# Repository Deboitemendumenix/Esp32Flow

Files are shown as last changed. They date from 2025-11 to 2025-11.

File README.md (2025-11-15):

# 💧 ESP32 Uroflowmetry Station

This project transforms an **ESP32** microcontroller and an **HX711** load cell amplifier into a web-enabled Uroflowmetry/Flow-Rate measurement device. It captures weight data over time, calculates the flow rate, and provides a web interface (HTML chart) and a CSV download for result analysis.

## ✨ Features

* **Wireless Data Acquisition:** Uses ESP32 Wi-Fi capabilities to host a web server for control and results.
* **High-Resolution Weighing:** Integrates the **HX711** Load Cell Amplifier for precise weight measurements.
* **Automatic Measurement Control:**
    * **Start Condition:** Measurement automatically begins when a weight greater than the `START_THRESHOLD` is detected.
    * **Stop Condition:** Measurement automatically stops after a period of stable weight (`STOP_TIMEOUT` and `STABILITY_TOLERANCE`).
* **Web Interface:** Serves a simple control page and a results page with an interactive **Google Chart** of Flow Rate and Volume over time.
* **Data Export:** Allows direct download of measurement data as a **CSV** file.
* **Status Indication:** Uses an **RGB LED** to visually indicate the device's current state.

---

## 🛠️ Hardware Requirements

* **ESP32 Development Board** (e.g., ESP32-WROOM-32)
* **HX711 Load Cell Amplifier**
* **1kg Load Cell**
* **RGB LED** or three single LEDs (common cathode/anode, adjust code accordingly)
* **Protoboard (5x7cm)**: Needed for mounting and wiring the components to fit within the case.
* **Power Supply** and associated wiring components.

---

## 📦 3D-Printed Case and Assembly

The project enclosure can be 3D printed using the provided files.

* The required **3mf files** are located in the **`models/`** folder of this repository.
* **Internal Components:** The case is designed to accommodate a **5x7cm protoboard** for mounting the ESP32 and HX711 components.
* **Assembly Hardware:** You will need the following screws for assembly:
    * **2x M4 screws** (16mm length)
    * **2x M5 screws** (16mm length)

---

## 📌 Pin Configuration

The following GPIO pins are used in the provided code.

| Component | Pin (GPIO) | Constant Name |
| :--- | :--- | :--- |
| **HX711 DOUT** | 18 | `LOADCELL_DOUT_PIN` |
| **HX711 SCK** | 16 | `LOADCELL_SCK_PIN` |
| **RGB LED Red** | 22 | `redPin` |
| **RGB LED Green** | 21 | `greenPin` |
| **RGB LED Blue** | 19 | `bluePin` |

---

## ⚙️ Setup and Calibration

### 1. Libraries

This project requires the following Arduino libraries:

* **HX711 Library** (e.g., from Bogdan R. or similar, commonly available in the Arduino Library Manager).
* **WiFi** (built-in for ESP32)
* **WebServer** (built-in for ESP32, usually found as `WebServer.h`)

### 2. Configuration

Before uploading, modify the following constants in the code (`#include <Arduino.h>...` section):

| Constant | Description | Default Value |
| :--- | :--- | :--- |
| `ssid` | Your Wi-Fi network name. | `"xxx"` |
| `password` | Your Wi-Fi network password. | `"xxx"` |
| `staticIP` | Static IP address. Leave empty `""` for DHCP (router-assigned), or specify an IP like `"192.168.1.100"`. | `""` (DHCP) |
| `gatewayIP` | Router gateway IP (used only if `staticIP` is configured). | `"192.168.1.1"` |
| `subnetMask` | Network subnet mask (used only if `staticIP` is configured). | `"255.255.255.0"` |
| `dnsServer` | DNS server (used only if `staticIP` is configured). | `"8.8.8.8"` |
| `CALIBRATION_FACTOR` | **Crucial:** Your load cell's specific calibration value (units per gram). **Must be determined experimentally.** | `-1025.42` |
| `START_THRESHOLD` | Minimum weight (in grams) to begin recording. | `1.0` |
| `STOP_TIMEOUT` | Duration (in ms) of stability before stopping the recording. | `10000` (10 seconds) |
| `STABILITY_TOLERANCE` | Allowable weight change (in grams) during the stop check. | `1.0` |

### 3. Calibration Process

You **must** calibrate your load cell/HX711 setup to find the correct `CALIBRATION_FACTOR`.

1.  Temporarily set `CALIBRATION_FACTOR` to `1.0`.
2.  Upload the code. The serial monitor will show the raw reading.
3.  Place a known weight (e.g., 100g) on the scale.
4.  The value printed to the serial monitor is your **Raw Reading**.
5.  Calculate the factor: **`CALIBRATION_FACTOR` = (Known Weight) / (Raw Reading)**. (Note: The result may be negative depending on your wiring).
6.  Replace the placeholder value with your calculated factor and upload the code again.

---

## 🚀 Usage

1.  **Connect Power:** Power up the ESP32.
2.  **Connect to Wi-Fi:** The device will attempt to connect to the configured Wi-Fi network.
3.  **Find IP:** Check the Serial Monitor to find the assigned **IP Address** or check your router to find the IP.
4.  **Access Web Server:** Open a web browser and navigate to the assigned IP address (e.g., `http://192.168.1.100`).
5.  **Control Page:** Click the **"Reset & Start New Measurement"** button. This tares the scale and sets the state to **IDLE**.
6.  **Measurement:** Place the object to be measured on the scale. Once the weight exceeds the `START_THRESHOLD`, the device will enter the **MEASURING** state and begin logging data.
7.  **Results:** Once the weight is stable for the `STOP_TIMEOUT`, the test will enter the **COMPLETED** state. View or download the results using the links on the main page.

---

## 🚥 Status Colors (RGB LED)

The RGB LED provides a quick visual indication of the system's status:

| State | Color | Description |
| :--- | :--- | :--- |
| `OFFLINE` | **Red** | Wi-Fi is disconnected or attempting to connect. |
| `IDLE` | **Green** | Ready for measurement. Awaiting weight change. |
| `MEASURING` | **Orange** | Actively recording weight and calculating flow rate. |
| `COMPLETED` | **Blue** | Measurement is complete and results are available. |
| `ERROR` | **Magenta** | Measurement was interrupted by a Wi-Fi disconnect. |

---

## 🖼️ Pictures

### Device

<div style="display:flex; gap:12px; align-items:center; flex-wrap:wrap;">
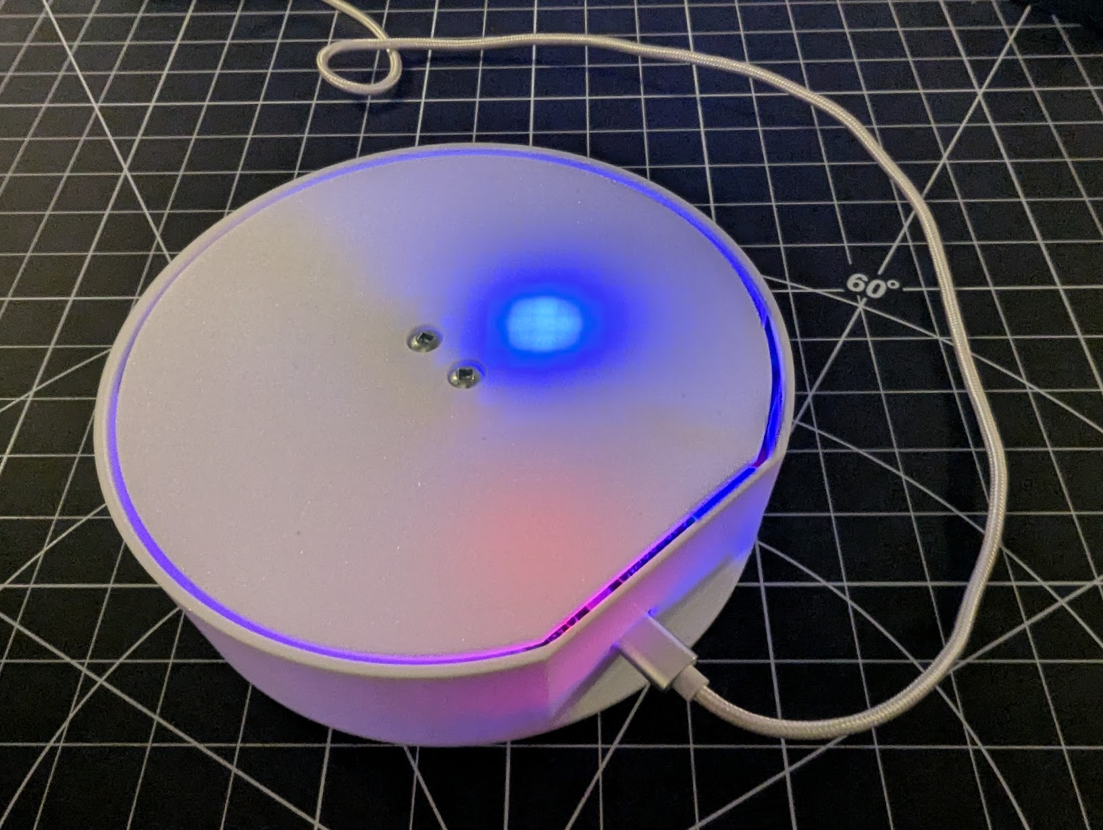
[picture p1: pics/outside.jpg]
OUtside view
    
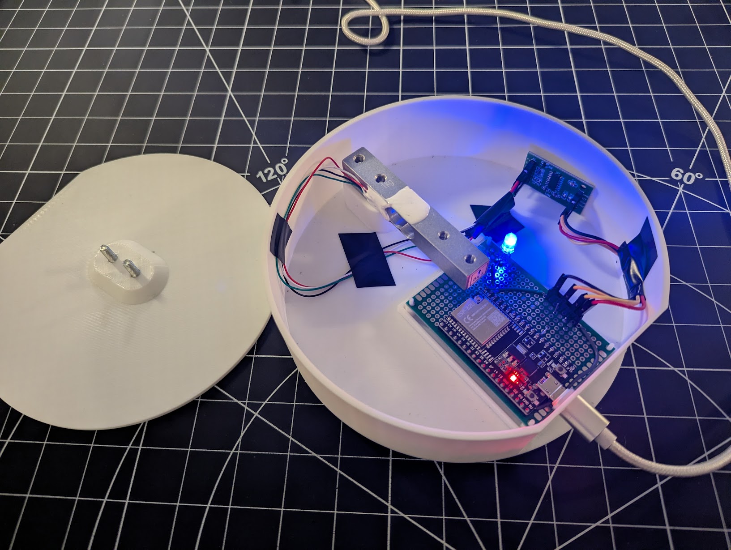
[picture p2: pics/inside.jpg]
Inside view
    
</div>

### Web interface

<div style="display:flex; gap:12px; align-items:center; flex-wrap:wrap;">
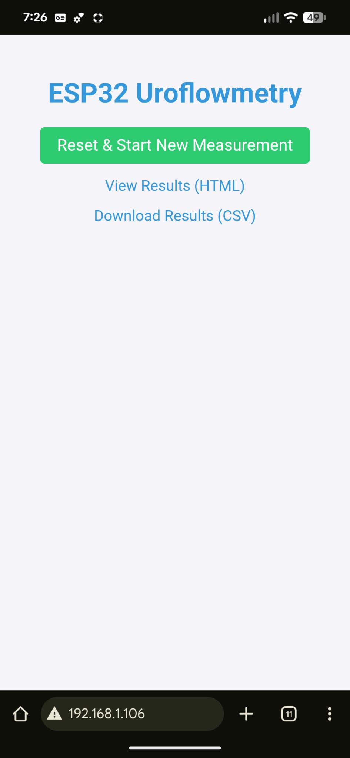
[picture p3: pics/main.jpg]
Main view
    
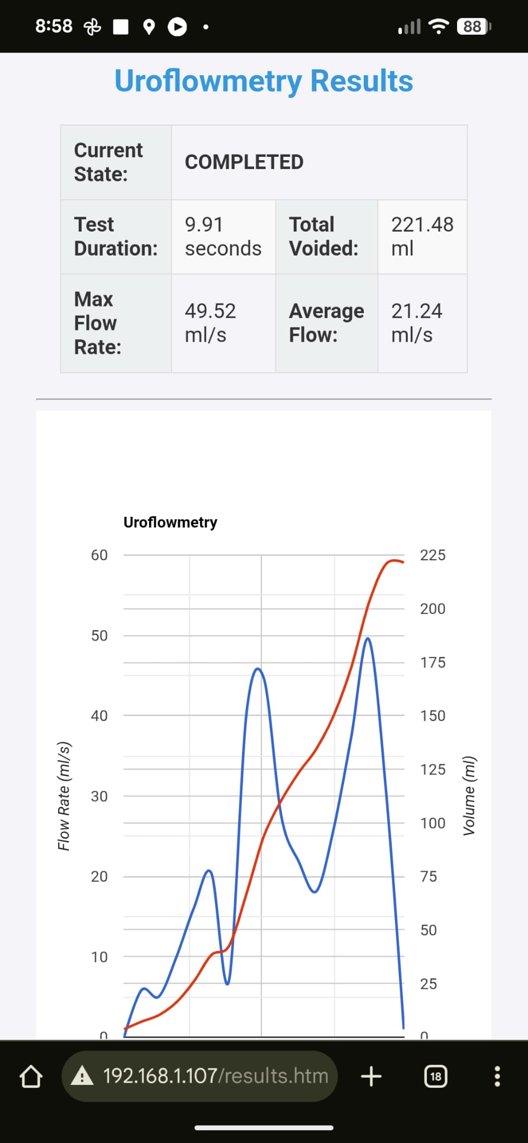
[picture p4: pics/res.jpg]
Result view
    
</div>

---

## 🤝 Contributing

This project is currently very simple, and contributions are highly encouraged!

If you have suggestions for new features, bug fixes, or improvements to the data processing or web interface, please feel free to open an issue or submit a **Pull Request**.

---

## 📜 License

This project is licensed under the MIT License — see the `LICENSE` file for details.

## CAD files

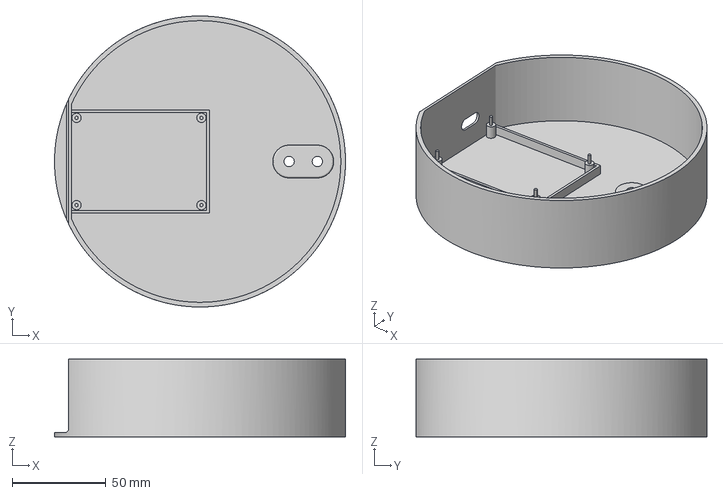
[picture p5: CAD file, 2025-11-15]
models/scale_container.3mf
155.0 x 155.0 x 41.5 mm

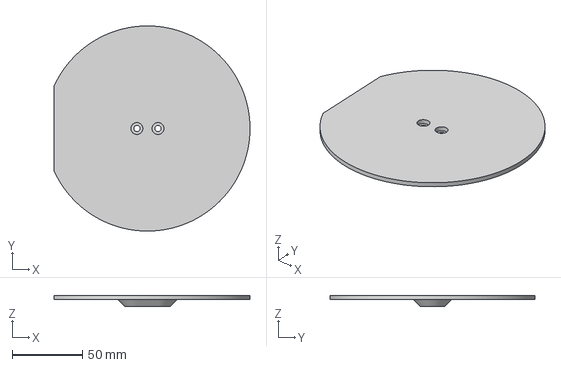
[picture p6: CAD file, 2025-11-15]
models/scale_lid.3mf
139.5 x 146.0 x 8.00 mm

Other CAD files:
models/scale_container.stl
models/scale_lid.stl

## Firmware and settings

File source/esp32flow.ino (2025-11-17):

/**
 * @file esp32flow.ino
 * @brief ESP32 Uroflowmetry Station - Flow-rate measurement device
 * @author Deboitemendumenix
 * @version 1.0.0
 * @license MIT License - See LICENSE file for details
 *
 * This project transforms an ESP32 with HX711 load cell amplifier into
 * a web-enabled uroflowmetry/flow-rate measurement device. It captures
 * weight data over time, calculates flow rate, and provides a web interface
 * with interactive charts and CSV data export.
 */

#include <Arduino.h>
#include "HX711.h"
#include <WiFi.h>
#include <WebServer.h>
#include <vector>
#include <ctime>
#include <freertos/semphr.h>
#include <freertos/FreeRTOS.h>
#include <freertos/task.h>

// ESP32 GPIO pins for HX711
const int LOADCELL_DOUT_PIN = 18;
const int LOADCELL_SCK_PIN = 16;

// RGB component
const int PWM_FREQ = 5000;    // PWM Frequency (5 kHz)
const int PWM_RESOLUTION = 8; // PWM Resolution (8 bits = 0 to 255 brightness levels)
const int RED_PIN = 22;
const int GREEN_PIN = 21;
const int BLUE_PIN = 19;

// WiFi configuration
const char *WIFI_SSID = "xxx";
const char *WIFI_PASSWORD = "xxx";
// Static IP configuration (leave empty "" for DHCP/router-assigned IP)
// Format: "192.168.1.100" for static, or "" for DHCP
const char *STATIC_IP = "192.168.1.106";
const char *GATEWAY_IP = "192.168.1.1";         // Router gateway (e.g., 192.168.1.1)
const char *SUBNET_MASK = "255.255.255.0";      // Subnet mask (typically 255.255.255.0)
const unsigned long RECONNECT_INTERVAL = 15000; // 15 seconds - WiFi reconnection retry interval
// Timing for WiFi reconnection attempts
unsigned long lastReconnectAttempt = 0;

// Duration of no flow to trigger STOP (in ms) (10 seconds)
const unsigned long STOP_TIMEOUT = 10000;

// Maximum test duration (in ms) (5 minutes)
const unsigned long MAX_TEST_DURATION = 300000;

// Threshold to START recording (in grams)
const float START_THRESHOLD = 2.0;

// Threshold to STOP recording (in ml/s)
// If flow stays below this value for STOP_TIMEOUT, the test ends.
const float STOP_FLOW_THRESHOLD = 2.0;

// Time between data points (in ms)
const unsigned long SAMPLING_INTERVAL = 500;

// Calibration factor, set your own value
// IMPORTANT: Must be calibrated experimentally. A value of 0 will cause silent failures.
const float CALIBRATION_FACTOR = -1025.42;

// Scale object
HX711 scale;

// Server object
WebServer server(80);

enum TestState
{
  OFFLINE,
  ERROR,
  IDLE,
  MEASURING,
  COMPLETED
};
// State of the esp32flow test
TestState currentState = OFFLINE;

// Data structure to store a single measurement
struct DataPoint
{
  unsigned long timeOffset; // Time in ms from start of test
  float weight;
  // Measured weight in g
  float flowRate;
  // Flow rate in g/s
};
std::vector<DataPoint> measurements;
SemaphoreHandle_t measurements_mutex;

// Timing variables
unsigned long lastSampleTime = 0;
unsigned long testStartTime = 0;
unsigned long stabilityStartTime = 0;

// Function prototypes
void setup();
void loop();
void setupWiFi();
void WiFiEvent(WiFiEvent_t event);
void setRGBColor(int red, int green, int blue);
void setupScale();
void resetTest();
void handleReset();
void setupWebServer();
void handleRoot();
void handleResultsCSV();
void handleNotFound();
String stateToString(TestState state);
void handleResultsHTML();
void taskMeasure(void *pvParameters);
void processWeightLogic(float currentWeight);

/**
 * @brief Main setup function.
 */
void setup()
{
  Serial.begin(115200);
  Serial.println("\n=== ESP32Flow Starting ===");
  setupScale();
  measurements_mutex = xSemaphoreCreateMutex();

  ledcAttach(RED_PIN, PWM_FREQ, PWM_RESOLUTION);
  ledcAttach(GREEN_PIN, PWM_FREQ, PWM_RESOLUTION);
  ledcAttach(BLUE_PIN, PWM_FREQ, PWM_RESOLUTION);

  // Reserve memory for 3 minutes of data at the given sampling interval.
  measurements.reserve((3 * 60 * 1000) / SAMPLING_INTERVAL);

  setupWiFi();
  setupWebServer();

  // Create pinned FreeRTOS task
  xTaskCreatePinnedToCore(taskMeasure, "measure", 4096, NULL, 2, NULL, 1);
}

/**
 * @brief Main loop function.
 */
void loop()
{
  updateLED(currentState);
  switch (currentState)
  {
  case OFFLINE:
  case ERROR:
    // Check if it's time to try reconnecting
    if (millis() - lastReconnectAttempt >= RECONNECT_INTERVAL)
    {
      Serial.println("Offline. Attempting WiFi reconnection...");
      WiFi.reconnect();
      lastReconnectAttempt = millis();
    }
    break;
  default:
    server.handleClient();
    break;
  }
}

/**
 * @brief Set the LED color based on state.
 */
void updateLED(TestState state)
{
  static TestState lastState = (TestState)-1;
  if (state == lastState)
  {
    return; // No change
  }
  switch (state)
  {
  case OFFLINE:
    setRGBColor(255, 0, 0); // Red
    break;
  case IDLE:
    setRGBColor(0, 255, 0); // Green
    break;
  case MEASURING:
    setRGBColor(255, 165, 0); // Orange
    break;
  case COMPLETED:
    setRGBColor(0, 0, 255); // Blue
    break;
  case ERROR:
    setRGBColor(255, 0, 255); // Magenta
    break;
  default:
    setRGBColor(0, 0, 0); // Off
    break;
  }
  lastState = state;
}

/**
 * @brief Initializes WiFi connection.
 */
void setupWiFi()
{
  updateLED(OFFLINE);
  WiFi.mode(WIFI_STA);
  WiFi.setAutoReconnect(true);
  WiFi.onEvent(WiFiEvent);

  // Apply static IP if configured, otherwise use DHCP
  if (strlen(STATIC_IP) > 0)
  {
    Serial.print("Configuring static IP: ");
    Serial.println(STATIC_IP);
    IPAddress ip;
    ip.fromString(STATIC_IP);
    IPAddress gateway;
    gateway.fromString(GATEWAY_IP);
    IPAddress subnet;
    subnet.fromString(SUBNET_MASK);
    WiFi.config(ip, gateway, subnet);
  }

  WiFi.begin(WIFI_SSID, WIFI_PASSWORD);
}

/**
 * @brief Handles WiFi state changes.
 */
void WiFiEvent(WiFiEvent_t event)
{
  switch (event)
  {
  case ARDUINO_EVENT_WIFI_STA_DISCONNECTED:
    Serial.println("Wi-Fi Disconnected....");
    lastReconnectAttempt = millis();
    if (currentState == MEASURING)
    {
      Serial.println("Aborting test due to disconnect.");
      currentState = ERROR;
      break;
    }
    currentState = OFFLINE;
    break;

  case ARDUINO_EVENT_WIFI_STA_GOT_IP:
    Serial.print("Wi-Fi Connected, IP Address: ");
    Serial.println(WiFi.localIP());
    currentState = COMPLETED;
    break;

  default:
    break;
  }
}

/**
 * @brief Sets the RGB LED color.
 */
void setRGBColor(int red, int green, int blue)
{
  ledcWrite(RED_PIN, red);
  ledcWrite(GREEN_PIN, green);
  ledcWrite(BLUE_PIN, blue);
}

/**
 * @brief Initializes and tares the HX711 scale.
 */
void setupScale()
{
  Serial.println("Initializing HX711...");
  scale.begin(LOADCELL_DOUT_PIN, LOADCELL_SCK_PIN);

  if (!scale.wait_ready_retry(10, 1000))
  {
    Serial.println("ERROR: HX711 not found. Check wiring and power.");
    return;
  }

  Serial.println("Taring...");
  scale.set_scale(CALIBRATION_FACTOR);
  scale.tare();
  Serial.println("Scale tared successfully.");
}

/**
 * @brief Clears data and tares scale.
 */
void resetTest()
{
  if (xSemaphoreTake(measurements_mutex, portMAX_DELAY) == pdTRUE)
  {
    measurements.clear();
    measurements.shrink_to_fit();

    Serial.println("Taring...");
    scale.tare();
    currentState = IDLE;
    Serial.println("Ready for new test.");
    xSemaphoreGive(measurements_mutex);
  }
}

/**
 * @brief Initializes the HTTP server.
 */
void setupWebServer()
{
  server.on("/", HTTP_GET, handleRoot);
  server.on("/index.html", HTTP_GET, handleRoot);
  server.on("/reset", HTTP_GET, handleReset);
  server.on("/results.html", HTTP_GET, handleResultsHTML);
  server.on("/results.csv", HTTP_GET, handleResultsCSV);
  server.onNotFound(handleNotFound);
  server.begin();
}

/**
 * @brief FreeRTOS task - Continuous Background Sampling
 * Reads raw data constantly, averages it, and triggers logic every 250ms.
 */
void taskMeasure(void *pvParameters)
{
  (void)pvParameters;
  const TickType_t delayTicks = pdMS_TO_TICKS(25);

  long readingAccumulator = 0;
  int readingCount = 0;
  unsigned long lastProcessTime = millis();

  for (;;)
  {
    // Accumulate Readings
    if (xSemaphoreTake(measurements_mutex, portMAX_DELAY) == pdTRUE)
    {
      if (scale.is_ready())
      {
        readingAccumulator += scale.read();
        readingCount++;
      }
      xSemaphoreGive(measurements_mutex);
    }

    // Process every SAMPLING_INTERVAL
    if (millis() - lastProcessTime >= SAMPLING_INTERVAL)
    {
      float currentWeight = 0;

      if (xSemaphoreTake(measurements_mutex, portMAX_DELAY) == pdTRUE)
      {
        // Calculate Average
        if (readingCount > 0)
        {
          long rawAverage = readingAccumulator / readingCount;
          currentWeight = (rawAverage - scale.get_offset()) / scale.get_scale();
        }
        else if (!measurements.empty())
        {
          currentWeight = measurements.back().weight;
        }

        // Pass averaged weight to the centralized logic
        processWeightLogic(currentWeight);

        // Reset accumulators
        readingAccumulator = 0;
        readingCount = 0;
        lastProcessTime = millis();

        xSemaphoreGive(measurements_mutex);
      }
    }

    vTaskDelay(delayTicks);
  }
}

/**
 * @brief Central Logic Handler (The State Machine)
 * Handles the entire lifecycle: Detection -> Recording -> Stop Check -> Finalizing
 */
void processWeightLogic(float currentWeight)
{
  unsigned long currentTime = millis();
  static int consistentWeidhtReadings = 0;

  switch (currentState)
  {
  case IDLE:
    if (currentWeight >= START_THRESHOLD)
    {
      consistentWeidhtReadings++;
      if (consistentWeidhtReadings >= 2)
      {
        Serial.println("Start detected: Switch to MEASURING");

        currentState = MEASURING;
        testStartTime = millis();
        stabilityStartTime = millis();

        // Add initial point (T=0)
        measurements.push_back({0, currentWeight, 0});
      }
    }
    else
    {
      // Reset counter if weight drops below threshold, likely noise.
      consistentWeidhtReadings = 0;
    }
    break;

  case MEASURING:
  {
    unsigned long timeOffset = currentTime - testStartTime;

    if (timeOffset > MAX_TEST_DURATION)
    {
      Serial.println("Max duration reached. Force stop.");
      currentState = COMPLETED;
      return;
    }

    // Calculate Flow Rate
    float flowRate = 0;
    if (!measurements.empty())
    {
      DataPoint lastPoint = measurements.back();
      // Ignore negative weight changes
      float deltaW = fmaxf(0.0f, currentWeight - lastPoint.weight);
      float deltaT = timeOffset - lastPoint.timeOffset;

      if (deltaT > 0)
      {
        float rawFlow = (deltaW * 1000.0f) / deltaT;
        // Low Pass Filter (50% new, 50% old)
        flowRate = (rawFlow * 0.5) + (lastPoint.flowRate * 0.5);
      }
    }

    // Store Data
    measurements.push_back({timeOffset, currentWeight, flowRate});

    // Check Stop Condition based on flow rate)
    if (flowRate > STOP_FLOW_THRESHOLD)
    {
      stabilityStartTime = millis();
    }
    else
    {
      // Flow is effectively zero (or very low) -> Check duration
      if (millis() - stabilityStartTime >= STOP_TIMEOUT)
      {
        Serial.println("Flow stopped. Finishing test.");
        currentState = COMPLETED;

        // Remove the data points recorded during the wait period
        unsigned long actualEndTime = stabilityStartTime - testStartTime;
        size_t trimIndex = measurements.size();

        for (size_t i = 0; i < measurements.size(); i++)
        {
          if (measurements[i].timeOffset > actualEndTime)
          {
            trimIndex = i;
            break;
          }
        }

        if (trimIndex < measurements.size())
        {
          measurements.resize(trimIndex);
        }

        Serial.print("Test Finalized. Duration: ");
        Serial.println(actualEndTime / 1000.0);
      }
    }
  }
  break;

  default:
    break;
  }
}

// CSV and HTTP constants
const char CSV_HEADER[] = "Time (ms),Weight (g),FlowRate (ml/s)\n";
const char CONTENT_TYPE_HTML[] = "text/html";
const char CONTENT_TYPE_CSV[] = "text/csv";
const char CONTENT_TYPE_PLAIN[] = "text/plain";

// HTML constant for main control page
const char htmlRoot[] = R"rawliteral(
<!DOCTYPE html>
<html>
<head>
 <title>ESP32 Uroflowmetry</title>
 <meta name="viewport" content="width=device-width, initial-scale=1">
 <style>
  body { font-family: sans-serif; text-align: center; padding: 20px; background-color: #f4f4f9; color: #333; }
  h1, h2 { color: #3498db; }
  button { 
   font-size: 1.2rem; 
   padding: 10px 20px; 
   cursor: pointer; 
   background-color: #2ecc71;
   color: white; 
   border: none; 
   border-radius: 5px; 
   transition: background-color 0.3s;
  }
  button:hover { background-color: #27ae60; }
  a { 
   display: block; 
   margin-top: 15px; 
   font-size: 1.1rem; 
   color: #3498db; 
   text-decoration: none; 
  }
  a:hover { text-decoration: underline; }
 </style>
</head>
<body>
 <h1>ESP32 Uroflowmetry</h1>
 
 <button id="startButton">Reset & Start New Measurement</button>
 <p id="status"></p>

 <a href="/results.html">View Results (HTML)</a>
 <a href="#" id="csvLink">Download Results (CSV)</a>

 <script>
  // Handle CSV download with client timezone
  document.getElementById('csvLink').addEventListener('click', function(e) {
   e.preventDefault();
   // Get client local time and format as YYYYMMDD_HHMMSS
   const now = new Date();
   const year = now.getFullYear();
   const month = String(now.getMonth() + 1).padStart(2, '0');
   const day = String(now.getDate()).padStart(2, '0');
   const hours = String(now.getHours()).padStart(2, '0');
   const minutes = String(now.getMinutes()).padStart(2, '0');
   const seconds = String(now.getSeconds()).padStart(2, '0');
   const timestamp = `${year}${month}${day}_${hours}${minutes}${seconds}`;
   
   // Create and trigger download with timestamped filename
   const link = document.createElement('a');
   link.href = '/results.csv?ts=' + timestamp;
   link.download = `uroflow_${timestamp}.csv`;
   link.click();
  });

  document.getElementById('startButton').addEventListener('click', function() {
   document.getElementById('status').innerText = 'Resetting...';
   fetch('/reset')
    .then(async response => {
     if (response.ok) {
      document.getElementById('status').innerText = 'Success! Ready to start measuring.';
     } else {
      const errorText = await response.text();
      document.getElementById('status').innerText = errorText;
     }
    })
    .catch(error => {
     document.getElementById('status').innerText = 'Connection error.';
    });
  });
 </script>
</body>
</html>
)rawliteral";

/**
 * @brief Serves the main control page.
 */
void handleRoot()
{
  server.send(200, CONTENT_TYPE_HTML, htmlRoot);
}

/**
 * @brief Serves results with chart/summary, streaming content to save memory.
 */
void handleResultsHTML()
{

  float totalVoided = 0.0;
  float maxFlowRate = 0.0;
  float totalFlowRateSum = 0.0;
  float testDuration = 0.0;
  String stateStr = stateToString(currentState);
  std::vector<DataPoint> measurementsCopy;

  if (xSemaphoreTake(measurements_mutex, portMAX_DELAY) == pdTRUE)
  {
    measurementsCopy = measurements;
    xSemaphoreGive(measurements_mutex);
  }
  if (!measurementsCopy.empty())
  {
    totalVoided = measurementsCopy.back().weight;
    testDuration = measurementsCopy.back().timeOffset / 1000.0;
    for (const auto &m : measurementsCopy)
    {
      totalFlowRateSum += m.flowRate;
      if (m.flowRate > maxFlowRate)
        maxFlowRate = m.flowRate;
    }
  }
  float averageFlow = (measurementsCopy.size() > 0) ? (totalFlowRateSum / measurementsCopy.size()) : 0.0;

  server.setContentLength(CONTENT_LENGTH_UNKNOWN);
  server.send(200, "text/html", "");

  server.sendContent(R"rawliteral(
<!DOCTYPE html><html><head>
<title>ESP32 Uroflowmetry</title>
<meta name="viewport" content="width=device-width, initial-scale=1">
<style>
 body { font-family: sans-serif; text-align: center; padding: 20px; background-color: #f4f4f9; color: #333; }
 h1, h2 { color: #3498db; }
 a { display: block; margin-top: 15px; font-size: 1.1rem; color: #3498db; text-decoration: none; }
 a:hover { text-decoration: underline; }
 .summary-table { margin: 20px auto; border-collapse: collapse; width: 80%; max-width: 600px; }
 .summary-table th, .summary-table td { padding: 10px; text-align: left; border: 1px solid #ddd; }
 .summary-table th { background-color: #ecf0f1; font-weight: bold; width: 40%; }
 .summary-table tr:nth-child(even) { background-color: #f9f9f9; }
</style>
<script type="text/javascript" src="https://www.gstatic.com/charts/loader.js"></script>
<script type="text/javascript">
 google.charts.load('current', {'packages':['corechart']});
 google.charts.setOnLoadCallback(drawChart);
 function drawChart() {
  var data = google.visualization.arrayToDataTable([
    ['Time (s)', 'Flow Rate (ml/s)', 'Volume (ml)'],
)rawliteral");

  if (measurementsCopy.empty())
  {
    server.sendContent("[0, 0, 0]");
  }
  else
  {
    for (size_t i = 0; i < measurementsCopy.size(); i++)
    {
      char row[100];
      snprintf(row, sizeof(row), "[%.2f,%.2f,%.2f]%s",
               measurementsCopy[i].timeOffset / 1000.0,
               measurementsCopy[i].flowRate,
               measurementsCopy[i].weight,
               (i < measurementsCopy.size() - 1) ? "," : "");
      server.sendContent(row);
    }
  }

  server.sendContent(R"rawliteral(
  ]);
  var options = {
    title: 'Uroflowmetry',
    curveType: 'function',
    legend: { position: 'bottom' },
    hAxis: { title: 'Time (seconds)' },
    vAxis: { title: 'Flow Rate (ml/s)' },
    series: {
      0: {targetAxisIndex: 0, labelInLegend: 'Flow Rate'},
      1: {targetAxisIndex: 1, labelInLegend: 'Volume'}
    },
    vAxes: {
      0: {title: 'Flow Rate (ml/s)'},
      1: {title: 'Volume (ml)'}
    }
  };
  var chart = new google.visualization.LineChart(document.getElementById('curve_chart'));
  chart.draw(data, options);
 }
</script>
</head><body>
<h2>Uroflowmetry Results</h2>
)rawliteral");

  server.sendContent("<table class='summary-table'>");
  server.sendContent("<tr><th>Current State:</th><td colspan='3'><b>" + stateStr + "</b></td></tr>");
  server.sendContent("<tr><th>Test Duration:</th><td>" + String(testDuration, 2) + " seconds</td>");
  server.sendContent("<th>Total Voided:</th><td>" + String(totalVoided, 2) + " ml</td></tr>");
  server.sendContent("<tr><th>Max Flow Rate:</th><td>" + String(maxFlowRate, 2) + " ml/s</td>");
  server.sendContent("<th>Average Flow:</th><td>" + String(averageFlow, 2) + " ml/s</td></tr>");
  server.sendContent("</table>");
  server.sendContent("<hr>");
  server.sendContent(R"rawliteral(
<div id="curve_chart" style="width: 100%; height: 600px"></div>
<hr>
<a href="/">&#9664; Back to Measurement Control</a>
</body></html>
)rawliteral");

  server.sendContent("");
}

/**
 * @brief Serves data as CSV with timestamped filename.
 * Uses client timezone timestamp from query parameter if available,
 * otherwise uses generic results.csv filename.
 */
void handleResultsCSV()
{
  // Get timestamp from query parameter (client timezone) if provided
  String filename = "results.csv";
  if (server.hasArg("ts"))
    filename = "uroflow_" + server.arg("ts") + ".csv";

  server.sendHeader("Content-Disposition", "attachment; filename=" + filename);
  server.setContentLength(CONTENT_LENGTH_UNKNOWN);
  server.send(200, CONTENT_TYPE_CSV, "");
  server.sendContent(CSV_HEADER);

  std::vector<DataPoint> measurementsCopy;
  if (xSemaphoreTake(measurements_mutex, portMAX_DELAY) == pdTRUE)
  {
    measurementsCopy = measurements;
    xSemaphoreGive(measurements_mutex);
  }

  for (const auto &m : measurementsCopy)
  {
    String line = String(m.timeOffset) + "," + String(m.weight, 2) + "," + String(m.flowRate, 2) + "\n";
    server.sendContent(line);
  }
  server.sendContent("");
}

/**
 * @brief Handles 404 errors.
 */
void handleNotFound()
{
  server.send(404, CONTENT_TYPE_PLAIN, "404: Not found");
}

/**
 * @brief Handles HTTP reset request.
 */
void handleReset()
{
  if (currentState == MEASURING)
  {
    server.send(412, "text/plain", "Cannot reset during measurement.");
    return;
  }
  resetTest();
  server.send(200, "text/plain", "Measurement reset. Waiting for start!");
}

/**
 * @brief Converts state enum to string.
 */
String stateToString(TestState state)
{
  switch (state)
  {
  case OFFLINE:
    return "OFFLINE";
  case IDLE:
    return "IDLE";
  case MEASURING:
    return "MEASURING";
  case COMPLETED:
    return "COMPLETED";
  default:
    return "UNKNOWN";
  }
}

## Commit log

2025-11-15 Squash: consolidated commit
    [scale_container.3mf, scale_lid.3mf]
2025-11-15 * Remove mutex * New Error state * Static IP option
    [esp32flow.ino]
2025-11-15 Add stl files.
    [scale_container.stl, scale_lid.stl]
